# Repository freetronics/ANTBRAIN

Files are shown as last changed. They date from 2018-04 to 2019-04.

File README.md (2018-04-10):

AntBrain Robot Controller
==========================
Copyright 2018 Freetronics Pty Ltd  www.freetronics.com  

The AntBrain is a tiny robot controller intended for ant-weight class
combat robots.

It uses the same ATmega328P MCU as the Arduino Uno, and adds 2 H-bridge
motor controllers to drive wheels and a servo output to control a
weapon. A radio control receiver mounts directly onto the board so the
Arduino can read the control signals.

Features:

 * ATmega328P MCU
 * 2 x L9110S H-bridge motor drivers
 * Mount for Flysky radio receiver
 * Servo output

You can view more online at:

  http://www.freetronics.com.au/antbrain

INSTALLATION
------------
The design is saved as an EAGLE project. EAGLE PCB design software is
available from www.cadsoftusa.com free for non-commercial use. To use
this project download it and place the directory containing these files
into the "eagle" directory on your computer. Then open EAGLE and
navigate to the project.

DISTRIBUTION
------------
The specific terms of distribution of this project are governed by the
license referenced below.

LICENSE
-------
Licensed under the TAPR Open Hardware License (www.tapr.org/OHL).
The "license" folder within this repository also contains a copy of
this license in plain text format.

CREDITS
-------
Designed by Jonathan Oxer (jon@freetronics.com)

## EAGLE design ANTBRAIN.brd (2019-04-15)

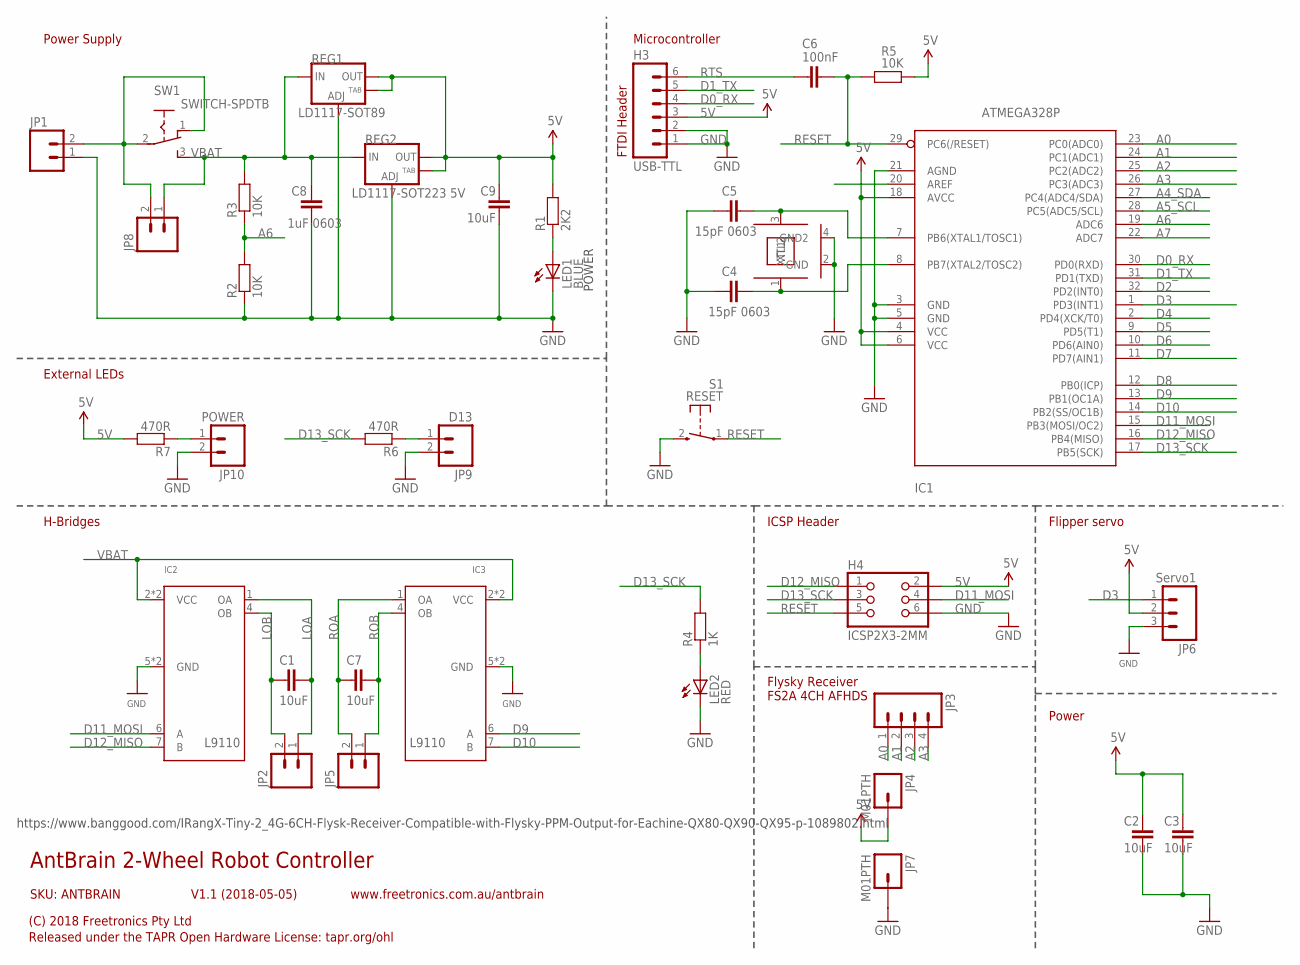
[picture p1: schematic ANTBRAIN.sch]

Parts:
C1, C2, C3, C7, C9: 10uF; 0805
C4, C5: 15pF 0603; 0603
C6: 100nF; 0603
C8: 1uF 0603; 0603
H3: USB-TTL; 1X06
H4: ICSP2X3-2MM; M2X3-2MM
IC1: ATMEGA328P; TQFP32-08
IC2, IC3: L9110SO8; SO08
JP1, JP2, JP5: M02PTH; 1X02
JP3: M04PTH; 1X04
JP4, JP7: M01PTH; 1X01
JP6: Servo1; 1X03
JP8: M022MM; M02-2MM
JP9: D13; M02-2MM
JP10: POWER; M02-2MM
LED1: BLUE; LED-0603
LED2: RED; LED-0603
R1: 2K2; 0603
R2, R3, R5: 10K; 0603
R4: 1K; 0603
R6, R7: 470R; 0603
REG1: LD1117-SOT89; SOT89
REG2: LD1117-SOT223 5V; SOT223
S1: RESET; TACTILE_SWITCH_SMD_2PIN_TINY
SW1: SWITCH-SPDTB; SPDT-2.5MM
XTL1: 16MHz; CRYSTAL-SMD-3X2

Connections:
5V: C2.1, C3.1, C9.1, H3.3, H4.2, IC1.4 (VCC), IC1.6 (VCC), IC1.18 (AVCC), JP4.1, JP6.2, R1.2, R5.2, R7.2, REG1.2 (OUT), REG1.4 (OUT), REG2.2 (OUT), REG2.4 (OUT)
A0: IC1.23 (PC0(ADC0)), JP3.1
A1: IC1.24 (PC1(ADC1)), JP3.2
A2: IC1.25 (PC2(ADC2)), JP3.3
A3: IC1.26 (PC3(ADC3)), JP3.4
A4_SDA: IC1.27 (PC4(ADC4/SDA))
A5_SCL: IC1.28 (PC5(ADC5/SCL))
A6: IC1.19 (ADC6), R2.2, R3.1
A7: IC1.22 (ADC7)
AREF: IC1.20 (AREF)
D0_RX: H3.4, IC1.30 (PD0(RXD))
D1_TX: H3.5, IC1.31 (PD1(TXD))
D2: IC1.32 (PD2(INT0))
D3: IC1.1 (PD3(INT1)), JP6.1
D4: IC1.2 (PD4(XCK/T0))
D5: IC1.9 (PD5(T1))
D6: IC1.10 (PD6(AIN0))
D7: IC1.11 (PD7(AIN1))
D8: IC1.12 (PB0(ICP))
D9: IC1.13 (PB1(OC1A)), IC3.6 (A)
D10: IC1.14 (PB2(SS/OC1B)), IC3.7 (B)
D11_MOSI: H4.4, IC1.15 (PB3(MOSI/OC2)), IC2.6 (A)
D12_MISO: H4.1, IC1.16 (PB4(MISO)), IC2.7 (B)
D13_SCK: H4.3, IC1.17 (PB5(SCK)), R4.2, R6.2
GND: C2.2, C3.2, C4.1, C5.1, C8.2, C9.2, H3.1, H3.2, H4.6, IC1.3 (GND), IC1.5 (GND), IC1.21 (AGND), IC2.5 (GND), IC2.8 (GND), IC3.5 (GND), IC3.8 (GND), JP1.1, JP6.3, JP7.1, JP9.2, JP10.2, LED1.C, LED2.C, R2.1, REG1.1 (ADJ), REG2.1 (ADJ), S1.2 (S), XTL1.2 (GND), XTL1.4 (GND2)
LOA: C1.1, IC2.1 (OA), JP2.1
LOB: C1.2, IC2.4 (OB), JP2.2
unnamed: LED2.A, R4.1
unnamed: JP10.1, R7.1
unnamed: JP9.1, R6.1
unnamed: JP1.2, JP8.2, SW1.1, SW1.2
unnamed: C5.2, IC1.7 (PB6(XTAL1/TOSC1)), XTL1.3 (XTL2)
unnamed: C4.2, IC1.8 (PB7(XTAL2/TOSC2)), XTL1.1 (XTL1)
unnamed: LED1.A, R1.1
RESET: C6.2, H4.5, IC1.29 (PC6(/RESET)), R5.1, S1.1
ROA: C7.2, IC3.1 (OA), JP5.2
ROB: C7.1, IC3.4 (OB), JP5.1
RTS: C6.1, H3.6
VBAT: C8.1, IC2.2 (VCC), IC2.3 (VCC), IC3.2 (VCC), IC3.3 (VCC), JP8.1, R3.2, REG1.3 (IN), REG2.3 (IN), SW1.3

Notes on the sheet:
AntBrain 2-Wheel Robot Controller
V1.1 (2018-05-05)
(C) 2018 Freetronics Pty Ltd
Released under the TAPR Open Hardware License: tapr.org/ohl
www.freetronics.com.au/antbrain
SKU: ANTBRAIN
https://www.banggood.com/IRangX-Tiny-2_4G-6CH-Flysk-Receiver-Compatible-with-Flysky-PPM-Output-for-Eachine-QX80-QX90-QX95-p-1089802.html
Power
ICSP Header
Microcontroller
FTDI Header
Flipper servo
POWER
Power Supply
H-Bridges
Flysky Receiver FS2A 4CH AFHDS
External LEDs

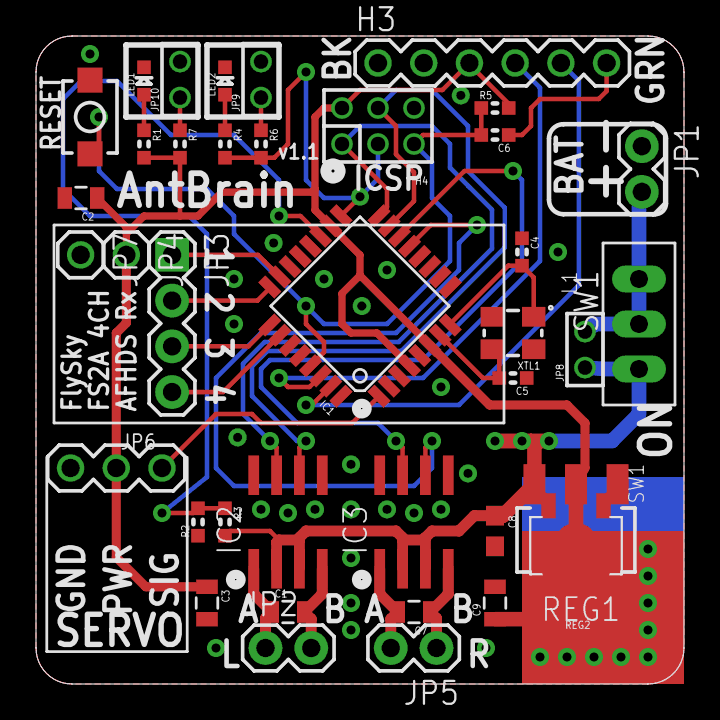
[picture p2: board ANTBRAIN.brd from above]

Board: 2 copper layers, 36.0 x 36.0 mm, 38 parts (0 on the bottom side), 29 nets.

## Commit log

2018-04-09 Initial project import
    [ANTBRAIN.brd, ANTBRAIN.sch]
2018-04-09 Shrunk board to 36x36mm
    [ANTBRAIN.brd, ANTBRAIN.sch]
2018-04-18 Finished routing for v1.0 release
    [ANTBRAIN.brd, ANTBRAIN.sch]
2018-06-08 Fixed H-Bridge footprints for v1.1 release
    [ANTBRAIN.brd, ANTBRAIN.sch]
2019-04-15 Silkscreen fixes
    [ANTBRAIN.brd]
